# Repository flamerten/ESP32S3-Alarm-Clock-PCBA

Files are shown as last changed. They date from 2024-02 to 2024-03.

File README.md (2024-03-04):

# ESP32 S3 Alarm Clock PCBA
I used KiCAD to design an ESP32S3 based alarm clock. It includes an IMU (LSM6DSOX), a RTC (PCF8523) and 29 WS2812-2020 LEDs for showing the time via 7 segment digits. The PCB was manufactured and assembled via JLCPB. This repository includes the schematic, layout and Arduino script for testing the various functions on the board. The firmware based on ESP-IDF is still in progress.

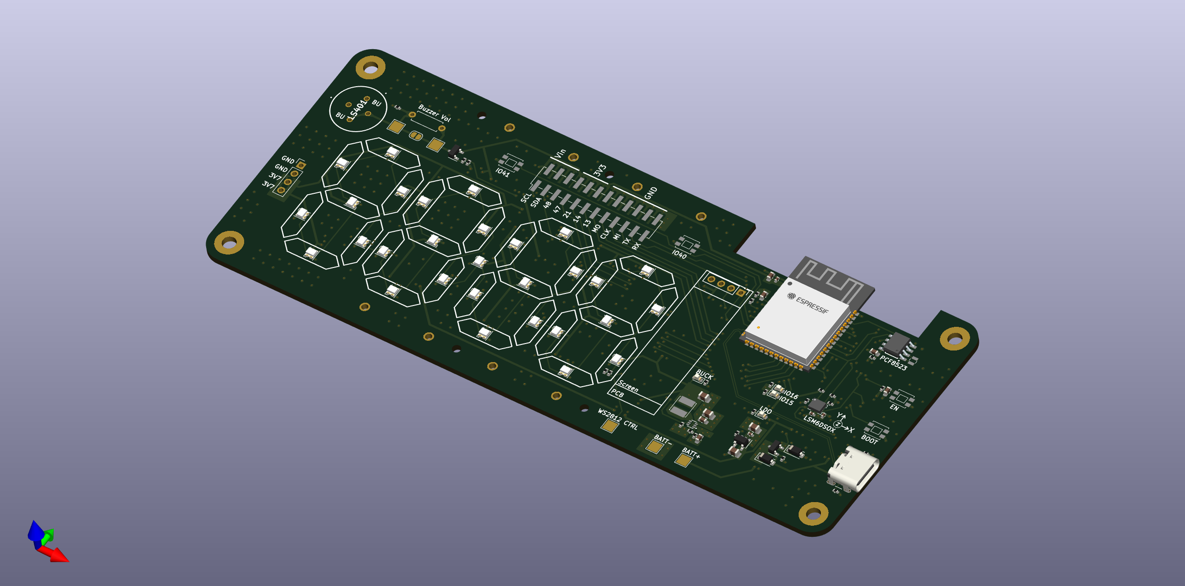
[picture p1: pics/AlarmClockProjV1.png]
Render

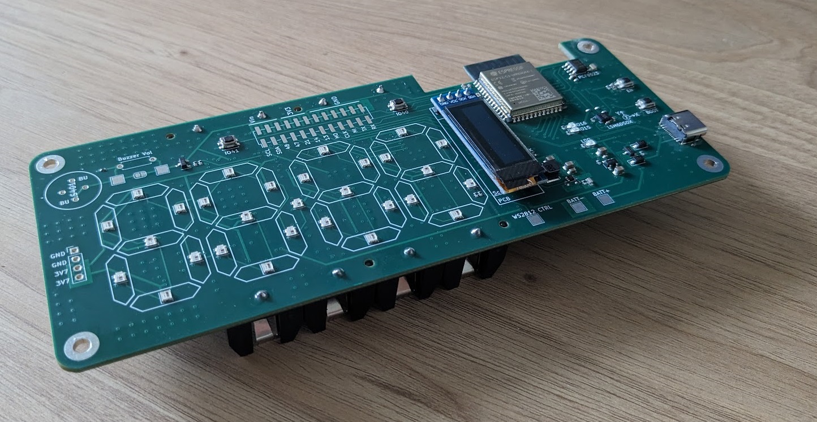
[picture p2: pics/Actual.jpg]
Actual


## Table of Contents
- [Schematic](#schematic)
- [Additional Notes](#additional-notes)

## Schematic
[Schematic Folder](./PCB/Schematic/)

The current schematic inlcudes some observations that I have made. For instance, I heard a high pitched noise from the switching regulator section, and that I could have added a switch to cut power to the whole board.

## Additional Notes
I used solidworks to design the dimensions of the 7-segment LED display, and converted it to a .dxf file format - [LED_Mapping.DXF](./LED_Mapping.DXF). This file was converted to a footprint and was used as a guide for the placement of LEDs.

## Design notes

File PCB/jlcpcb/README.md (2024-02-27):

# JLCPCB Files
Files in this folder are sent to JLCPCB for manufacturing. This file also includes the BOM and their respective LCSC parts. However, I sourced for the through hole components myself and soldered them.

- [Battery Holder](https://www.aliexpress.com/item/1005006254465094.html?spm=a2g0o)
- [OLED Breakout](https://www.aliexpress.com/item/1005005973981064.html?spm=a2g0o)
- [SMD Pin Header 02x12](https://www.aliexpress.com/item/33056177154.html?spm=a2g0o)
- [PS1240 Passive Buzzer](https://www.aliexpress.com/item/1005005731967986.html?spm=a2g0o)

## Ordering
I designed the PCB with KiCAD, and installed the [kicad-jlcpcb-tools](https://github.com/bouni/kicad-jlcpcb-tools) plugin which automatically generates the neccessary files. The [Gerber Files](./production_files/GERBER-AlarmClockProjV1.zip) are used first, followed by the [BOM File](./production_files/BOM-AlarmClockProjV1.csv) and [CPL File](./production_files/CPL-AlarmClockProjV1.csv). 

To reduce cost, I opted for single sided assembly, with no through hole components. The assembly was **standard** because of the ESP32 module and the WS2812B. 

I was recommended by JLCPCB to bake the WS2812-2020 component as it was moisture sensitive, which increased the assembly by $7.54.

Note that component rotation is mandatory. I had to check all the components and rotate them myself, not too sure why. Resistors and Capacitors were okay, but the MOSFETS, ICs and LEDs had to be rotated.

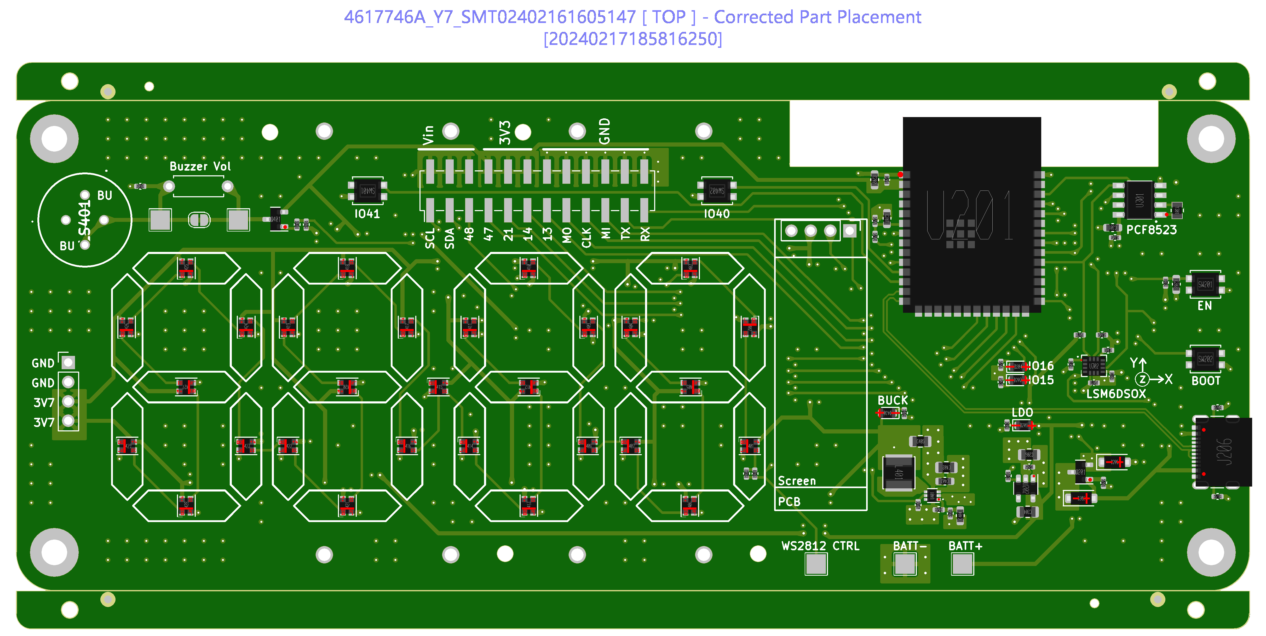
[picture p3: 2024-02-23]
PCB/jlcpcb/4617746A_Y7/49155830063104-Produce_DanZhi.SMT_Snapshot.Top.4617746A_Y7.SMT02402161605147.png

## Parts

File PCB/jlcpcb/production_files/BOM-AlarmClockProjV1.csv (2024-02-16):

Comment | Designator | Footprint | LCSC
1k | R204,R206,R208,R305,R401,R403,R404,R405,R409 | R_0402_1005Metric | C11702
100nF | C201,C205,C304,C305 | C_0402_1005Metric | C1525
ZXMP3A13FTA | Q201,Q401 | SOT-23-Alt | C156326
1uF | C202,C203,C207,C301,C403 | C_0603_1608Metric | C15849
10uF | C204,C206,C402,C405 | C_0805_2012Metric | C15850
33pF | C404 | C_0603_1608Metric | C190578
KT-0805Y | D201,D203,D204,D430 | LED_0603_1608Metric | C2296
100k | R202,R203,R205,R207 | R_0402_1005Metric | C25741
10k | R201,R301,R302,R303,R304,R402,R406,R408 | R_0402_1005Metric | C25744
5K1 | R209,R210 | R_0402_1005Metric | C25905
PCF8523T_1,118 | U301 | SOIC127P600X175-8N | C2651516
ESP32-S3-WROOM-1(N4) | U201 | ESP32S3WROOM1N8R8 | C2913197
RT5760CHGH6F | U401 | SOT-563 | C2976591
XKB Tactile | SW201,SW202,SW401,SW402 | XKB Tactile SW | C318879
51k | R407 | R_0402_1005Metric | C319542
1054500101 | J206 | USB_C_Receptacle_GCT_USB4105-xx-A_16P_TopMnt_Horizontal | C393939
4.7uH | L401 | GLE GCNR4030 4mmx4mm Inductor | C439356
LSM6DSOXTR | U302 | LSM6DSOX | C481766
AP2112K-3.3 | U202 | SOT-23-5 | C51118
BH-AA-A5BJ012 | J202,J203,J204,J205 | MYOUNG AA Bat Holder | C5290180
B5817W | D202,D205 | D_SOD-123 | C8597
PS1440P02BT | LS401 | PS1240P02BT | C96060
WS2812B-2020 | D401,D402,D403,D404,D405,D406,D407,D408,D409,D410,D411,D412,D413,D414,D415,D416,D417,D418,D419,D420,D421,D422,D423,D424,D425,D426,D427,D428,D429 | LED_WS2812B-2020_PLCC4_2.0x2.0mm | C965555
Seiko 32.768kHz | Y301 | Seiko Crustal | C99009
Conn_02x12_Odd_Even | J201 | PinHeader_2x12_P2.54mm_Vertical_SMD
Conn_01x04_Pin | J402 | PinHeader_1x04_P2.54mm_Vertical
Conn_01x04_Pin | J301 | 128x32_OLED_Breakout

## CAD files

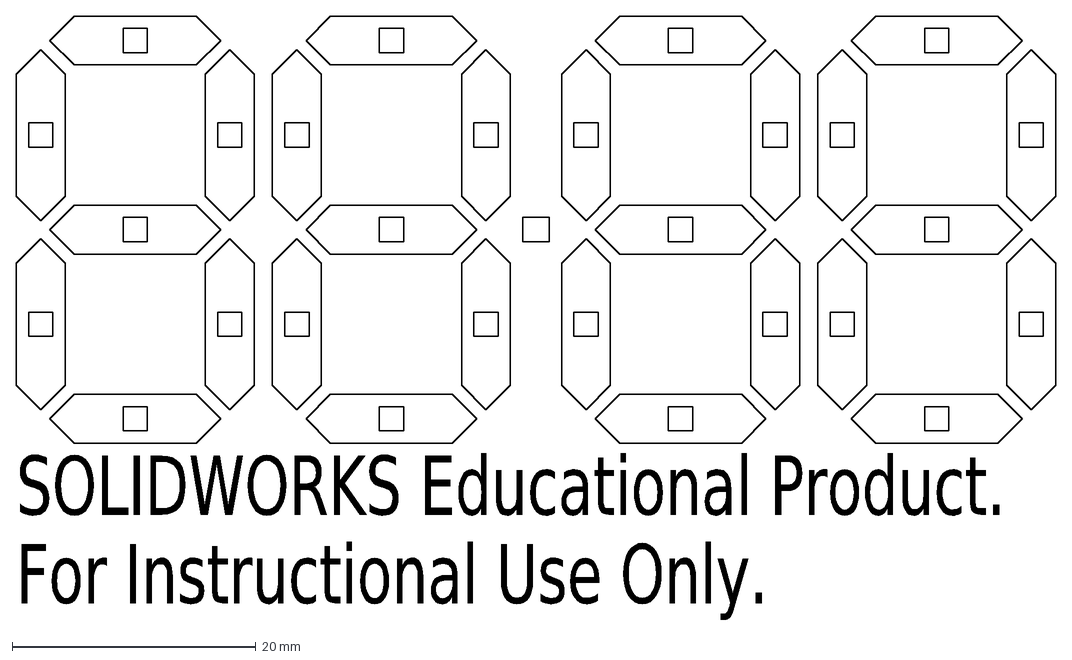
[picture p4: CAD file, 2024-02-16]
LED_Mapping.DXF
SOLIDWORKS Educational Product.
For Instructional Use Only.

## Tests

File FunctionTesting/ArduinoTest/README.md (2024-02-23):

# ArduinoTest

Used to test various functionalities of the PCB. 

## To Be Done
- Buzzer

## Arduino IDE Upload
[Source: USB and CDC Flashing](https://docs.espressif.com/projects/arduino-esp32/en/latest/tutorials/cdc_dfu_flash.html)

USB CDC is used to upload and view debugging messages
1. To enter into the download mode, you need to press and hold BOOT button and press and release the RESET button. You should see a new USB device with the name ESP32S3 Dev Kit listed in available ports. Select the device.
2. Configuration
- USB CDC On Boot -> Enabled
- Upload Mode -> UART0 / Hardware CDC
- USB Mode -> Hardware CDC & JTAG

Full configuration from "Tools" is here
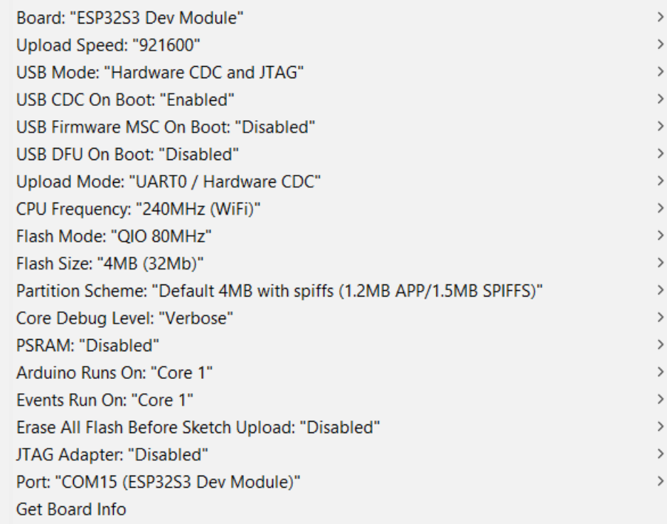
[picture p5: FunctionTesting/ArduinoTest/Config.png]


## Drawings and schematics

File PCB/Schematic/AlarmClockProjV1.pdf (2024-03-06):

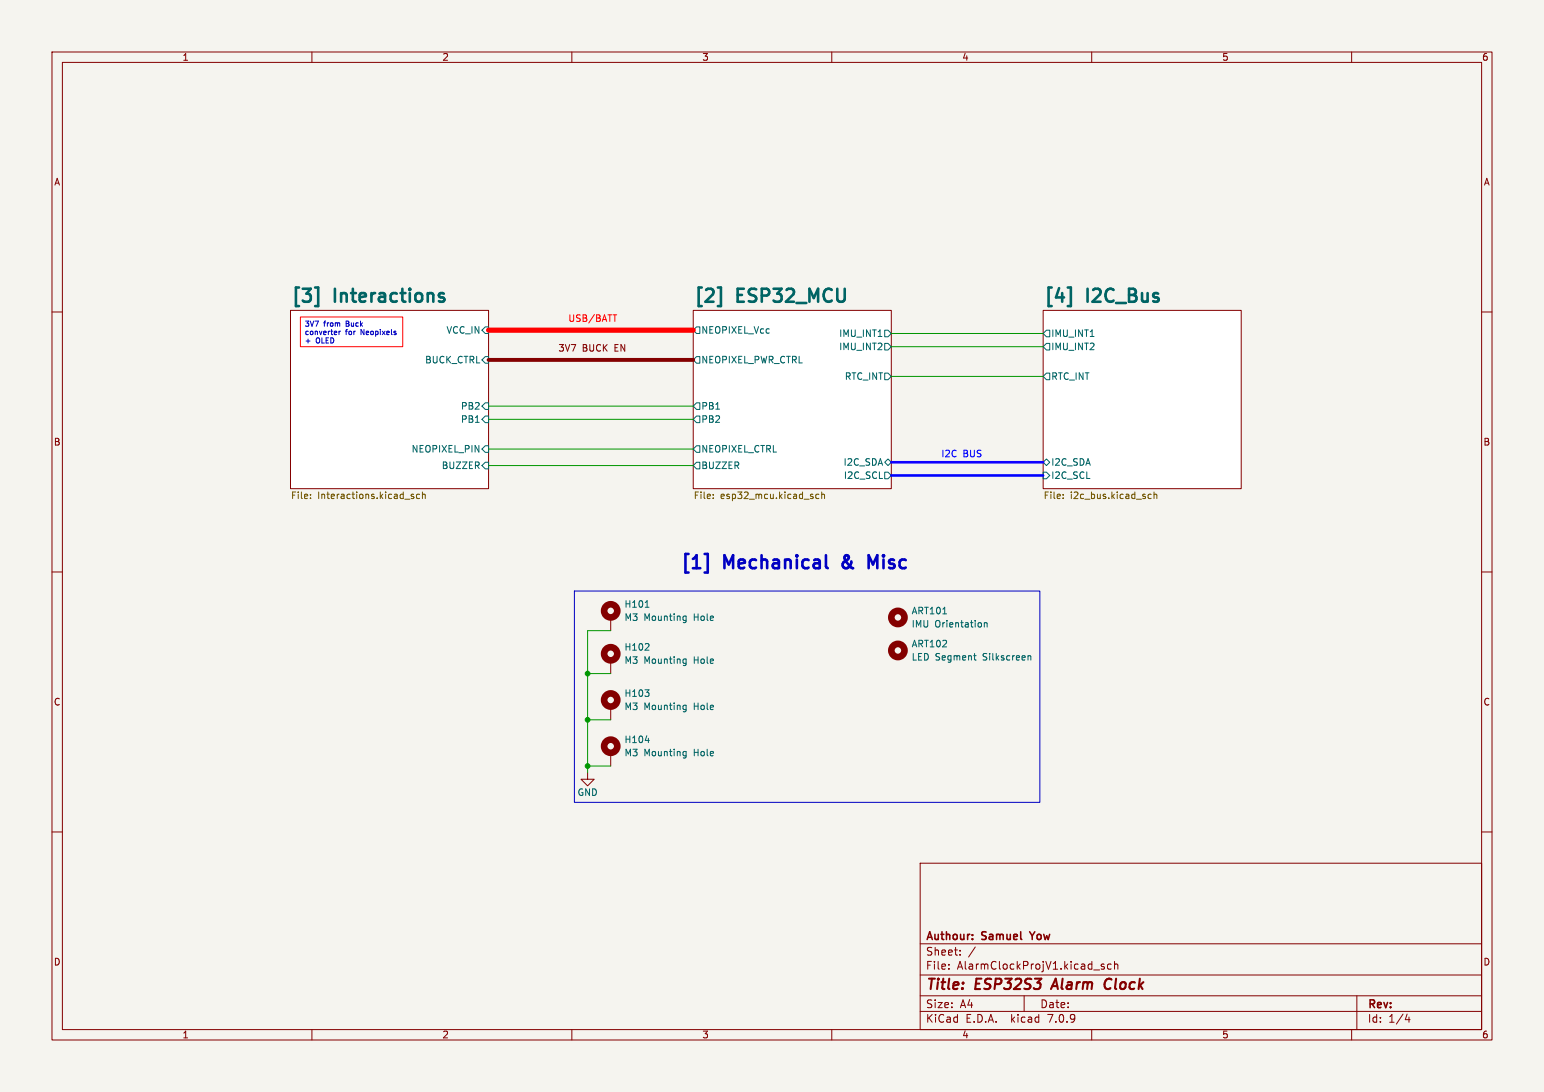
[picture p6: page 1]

IMU Orientation H101 M3 Mounting Hole GND

H103 M3 Mounting Hole H104 M3 Mounting Hole

File: AlarmClockProjV1.kicad_sch Sheet: / Authour: Samuel Yow

Id: 1/4 Title: ESP32S3 Alarm Clock

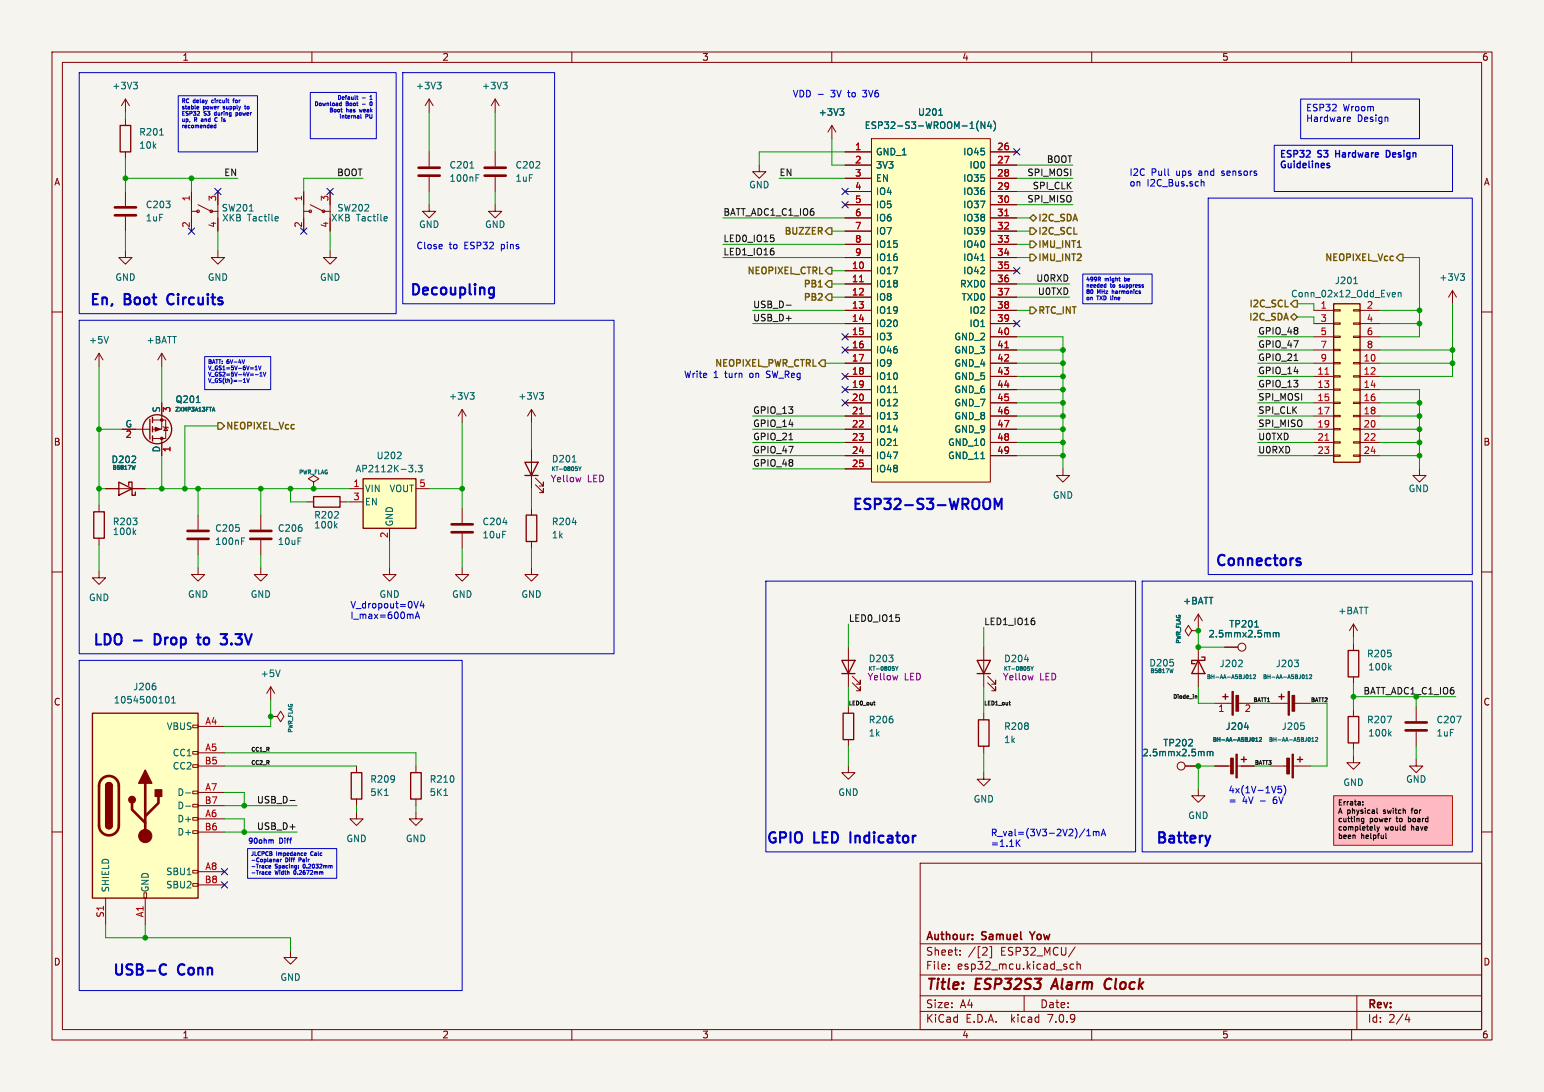
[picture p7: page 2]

VDD - 3V to 3V6 LDO - Drop to 3.3V
J201 Conn_02x12_Odd_Even R201

RC delay circuit for stable power supply to ESP32 S3 during power up, R and C is

3 4 SW202 XKB Tactile GND GND

Id: 2/4 Title: ESP32S3 Alarm Clock

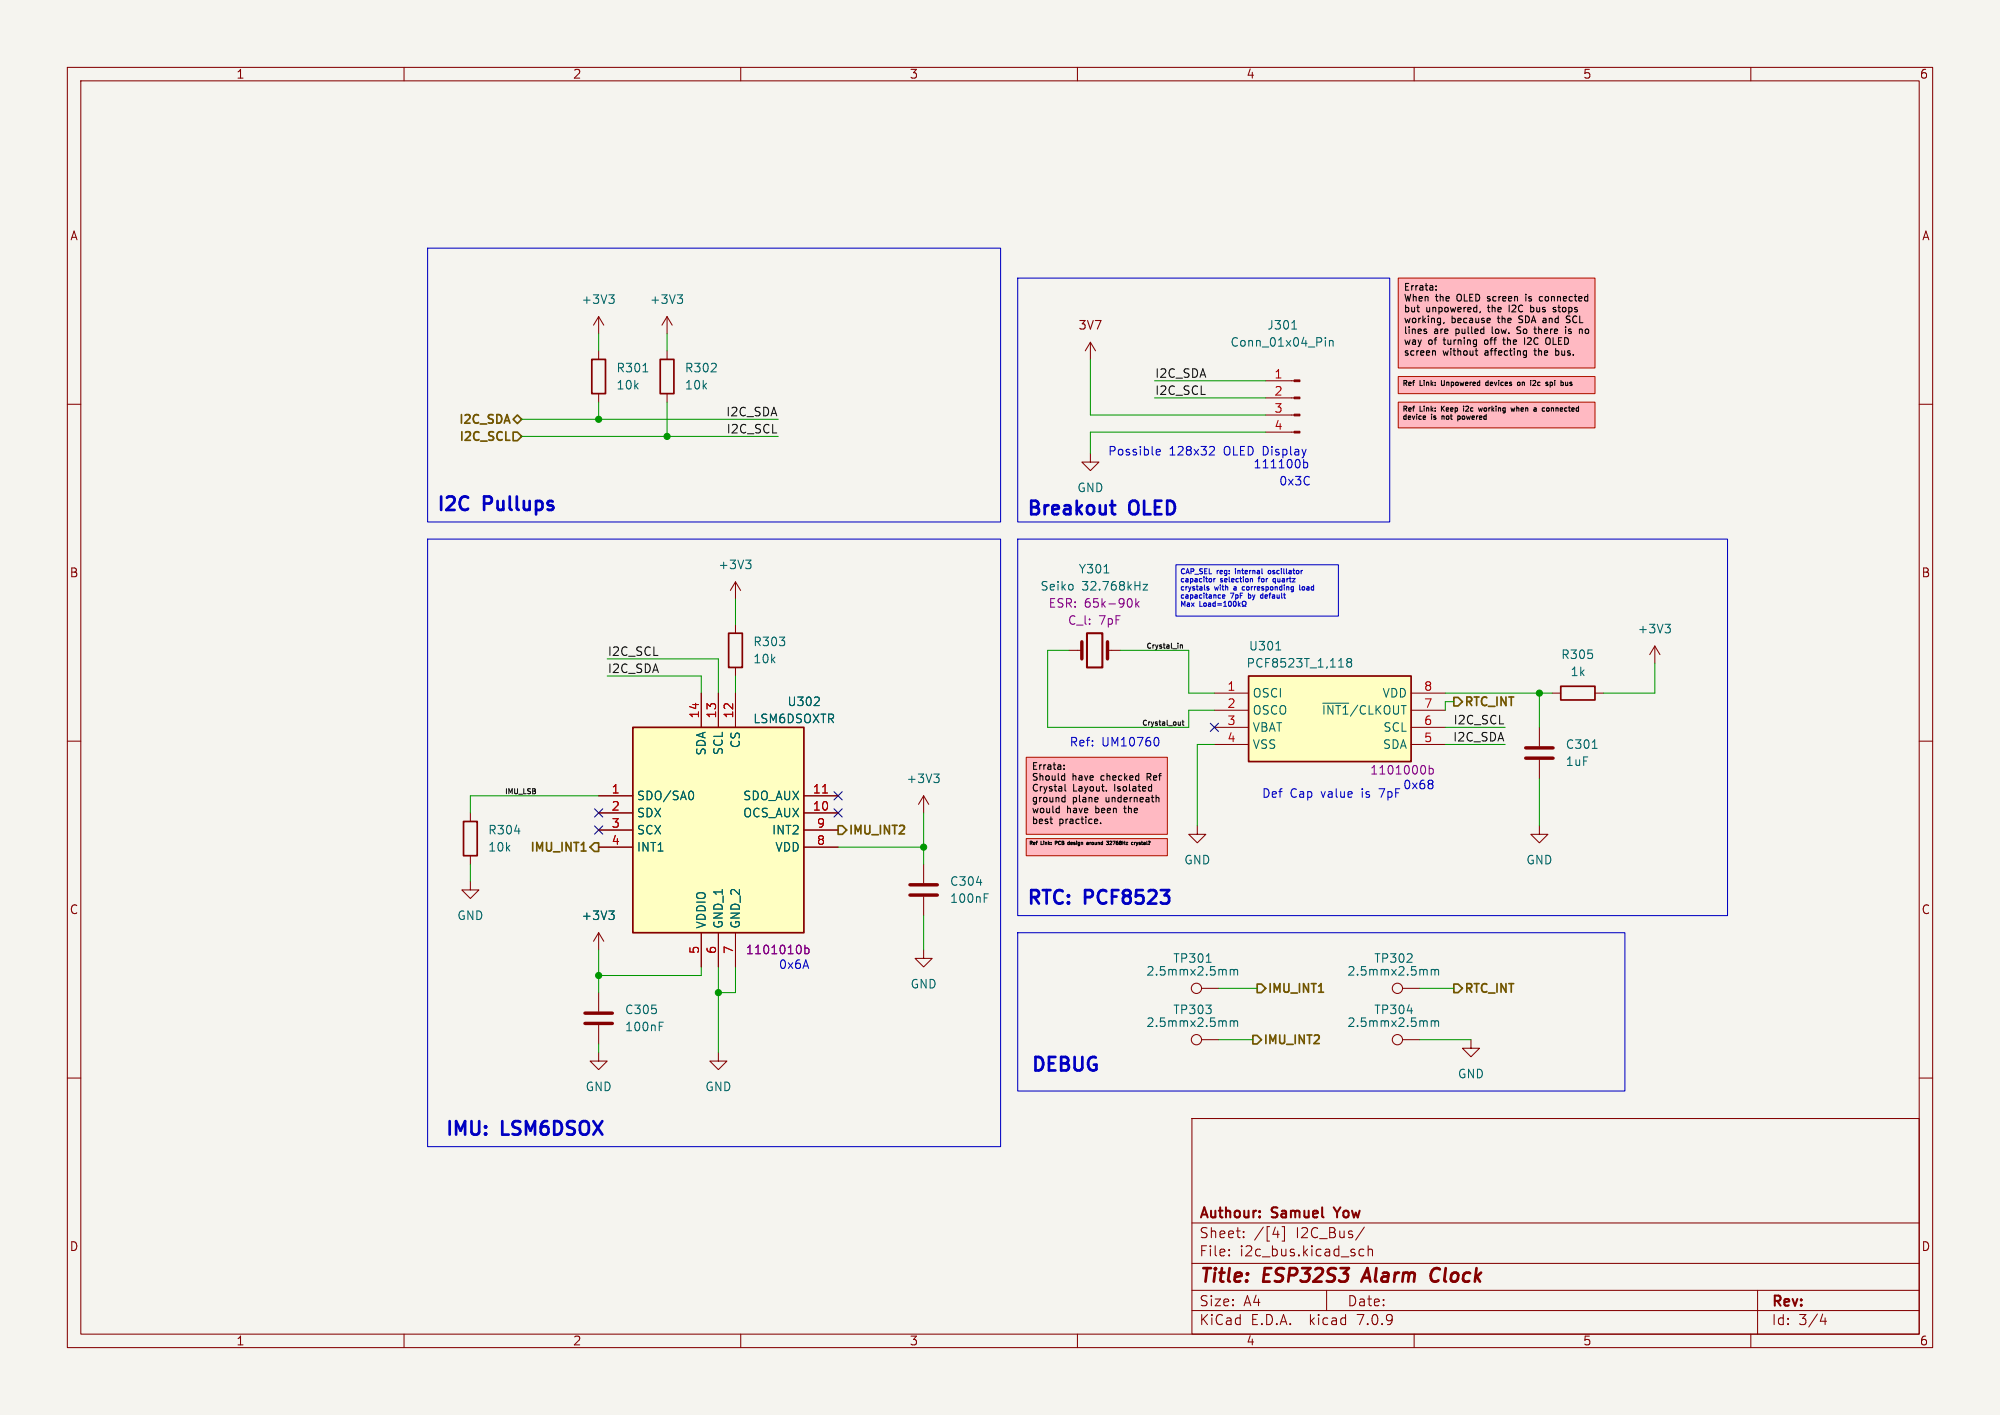
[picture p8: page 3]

device is not powered (https://forum.arduino.cc/t/keep-i2c-working-when-a-connected-device-is-not-powered/390732) Ref Link: Unpowered devices on i2c spi bus Errata: When the OLED screen is connected

Ref Link: Keep i2c working when a connected

Def Cap value is 7pF0x68

ground plane underneath would have been the

Id: 3/4 Title: ESP32S3 Alarm Clock

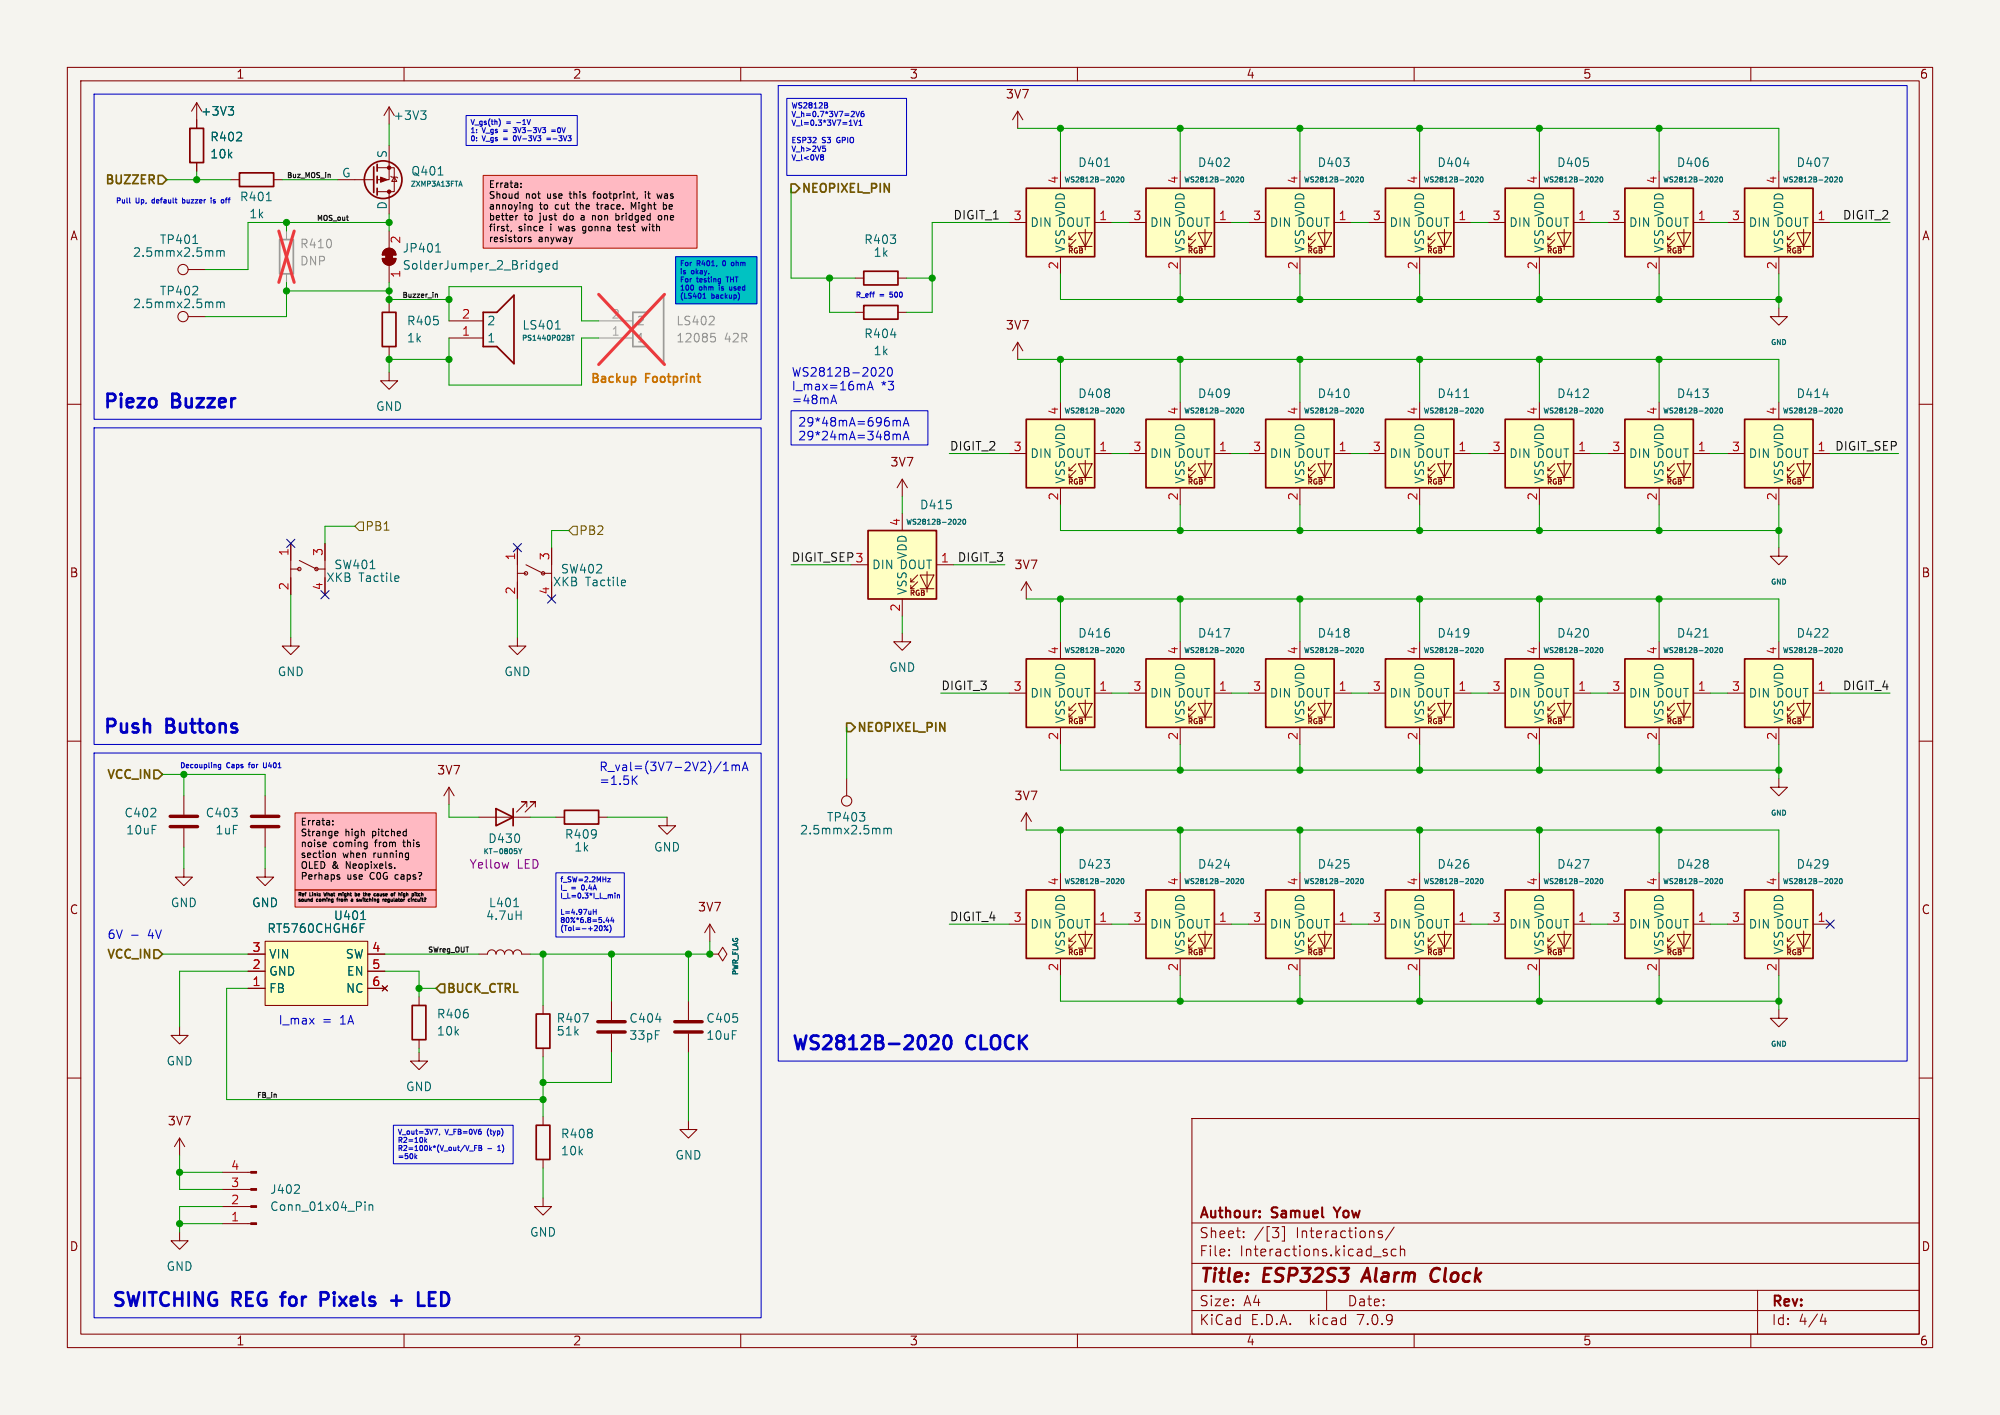
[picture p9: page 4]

4 D407 WS2812B-2020 GND GND RGB DOUT 1 VSS

better to just do a non bridged one
first, since i was gonna test with

Errata: Strange high pitched

noise coming from this

Ref Link: What might be the cause of high pitch

Id: 4/4 Title: ESP32S3 Alarm Clock

SWITCHING REG for Pixels + LED

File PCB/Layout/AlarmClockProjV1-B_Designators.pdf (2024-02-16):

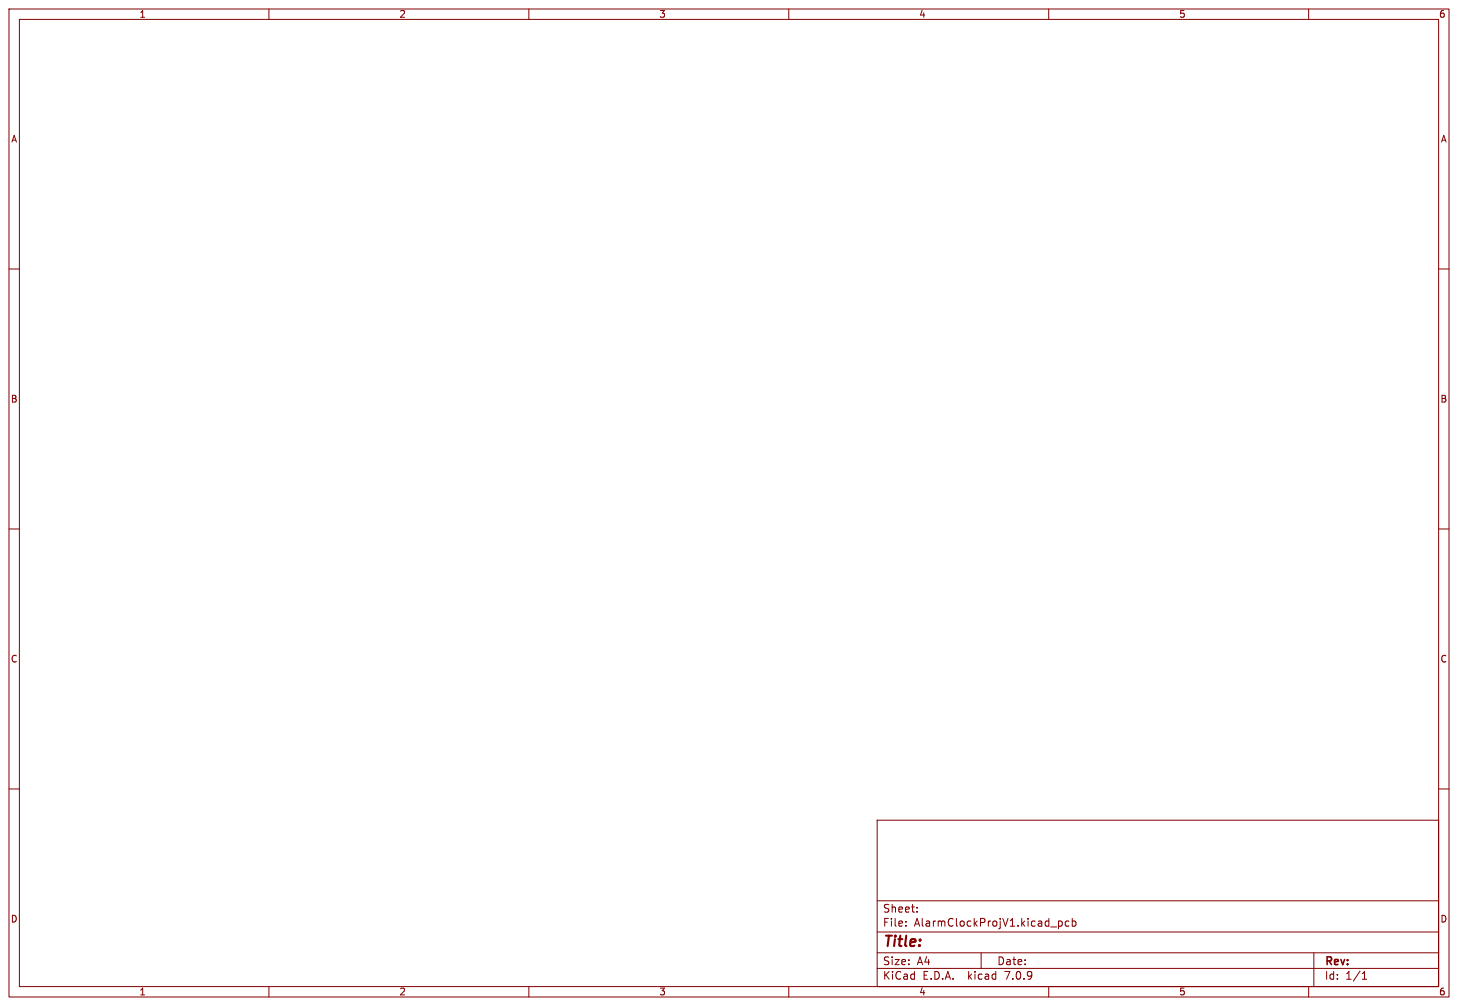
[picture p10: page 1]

Id: 1/1 Title: File: AlarmClockProjV1.kicad_pcb Sheet:

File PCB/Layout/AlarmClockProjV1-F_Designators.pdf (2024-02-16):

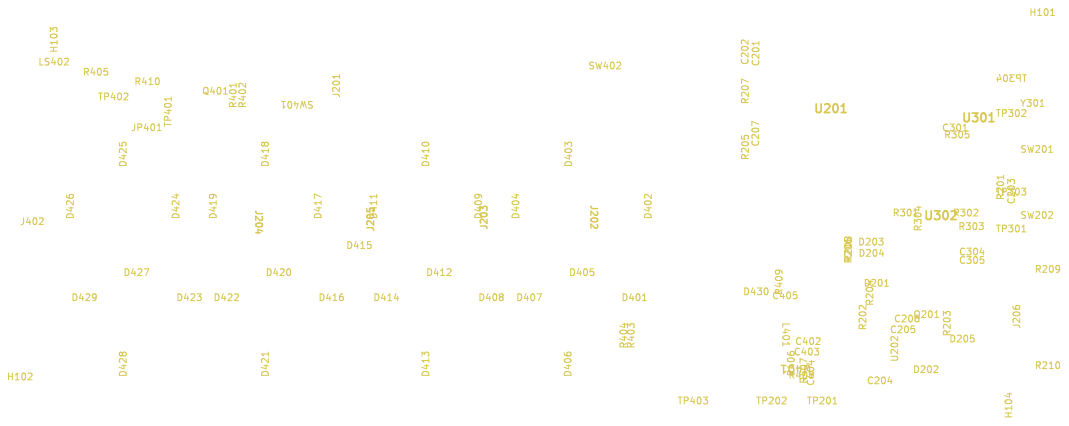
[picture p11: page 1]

Id: 1/1 Title: File: AlarmClockProjV1.kicad_pcb Sheet: R207

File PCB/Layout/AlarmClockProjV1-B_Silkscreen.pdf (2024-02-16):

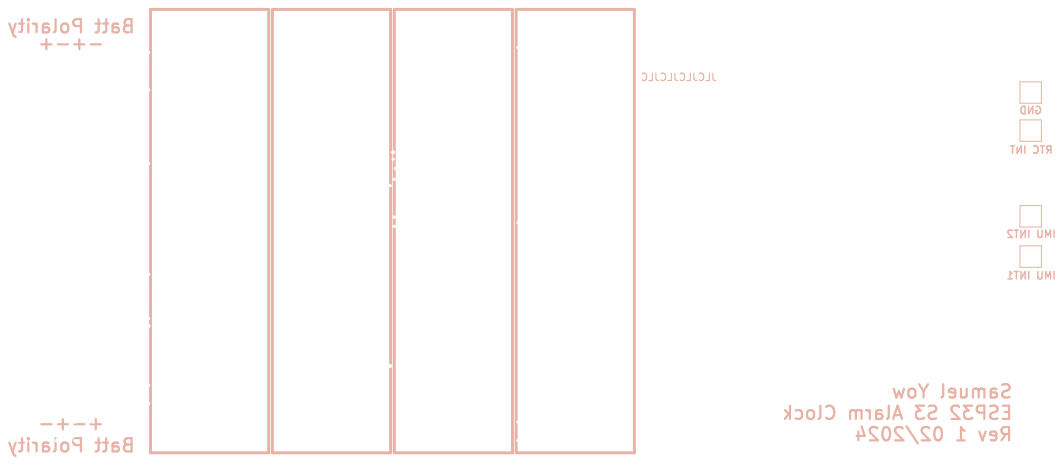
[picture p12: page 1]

Id: 1/1 Title: File: AlarmClockProjV1.kicad_pcb Sheet:

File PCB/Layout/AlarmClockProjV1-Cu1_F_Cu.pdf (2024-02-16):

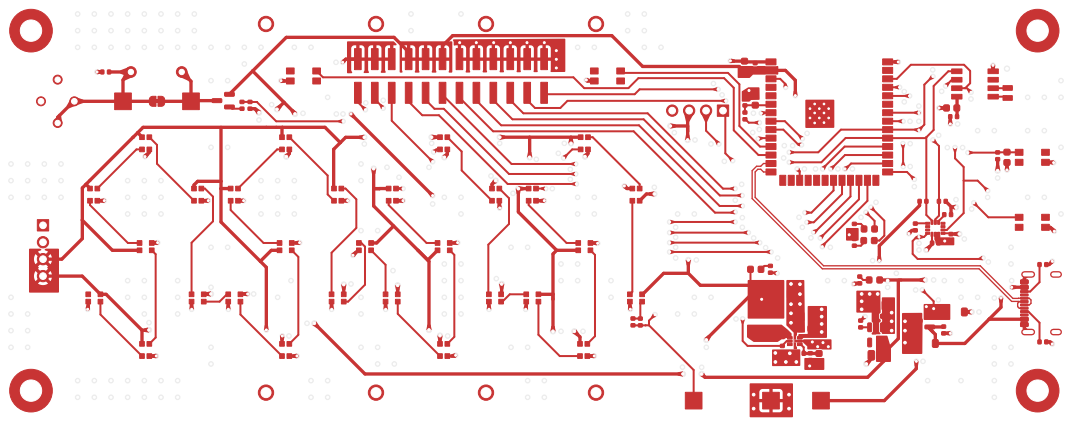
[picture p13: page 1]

Id: 1/1 Title: File: AlarmClockProjV1.kicad_pcb Sheet:

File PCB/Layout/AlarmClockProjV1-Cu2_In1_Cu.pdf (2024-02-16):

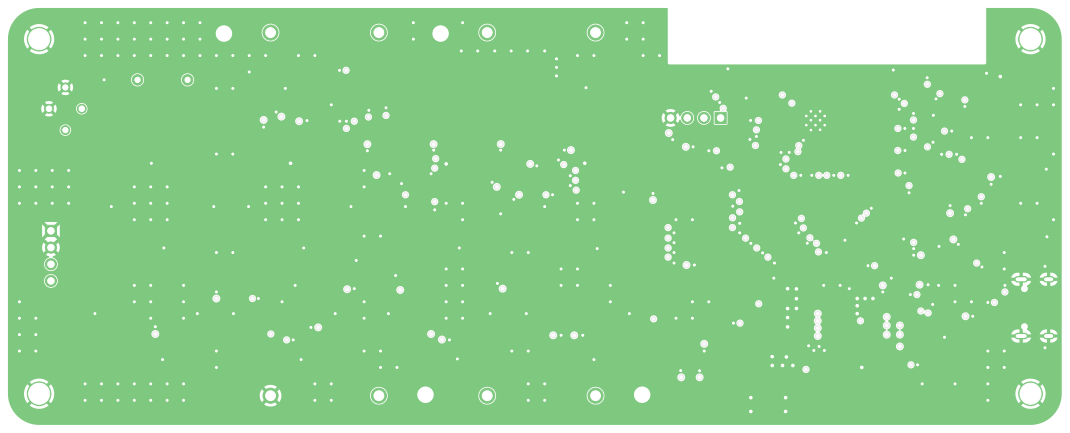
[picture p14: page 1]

Id: 1/1 Title: File: AlarmClockProjV1.kicad_pcb Sheet:

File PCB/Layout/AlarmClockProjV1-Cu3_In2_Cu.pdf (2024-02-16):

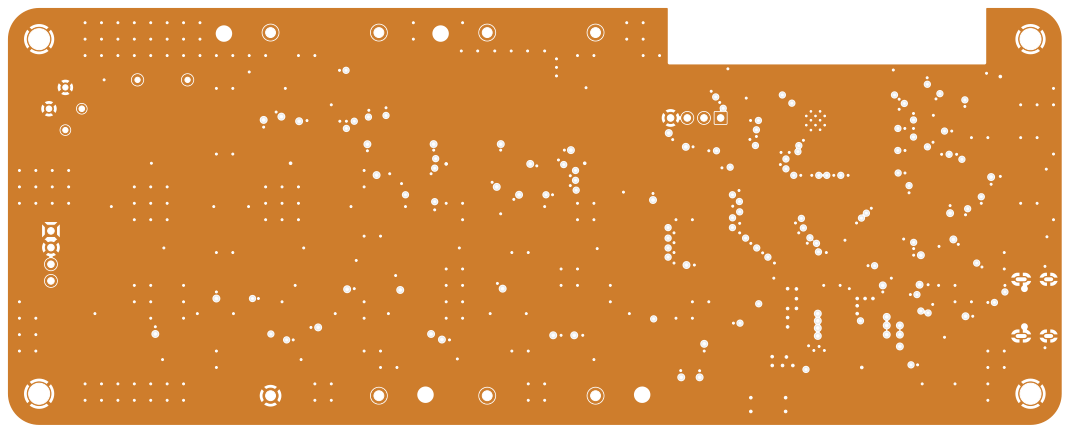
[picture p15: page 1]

Id: 1/1 Title: File: AlarmClockProjV1.kicad_pcb Sheet:

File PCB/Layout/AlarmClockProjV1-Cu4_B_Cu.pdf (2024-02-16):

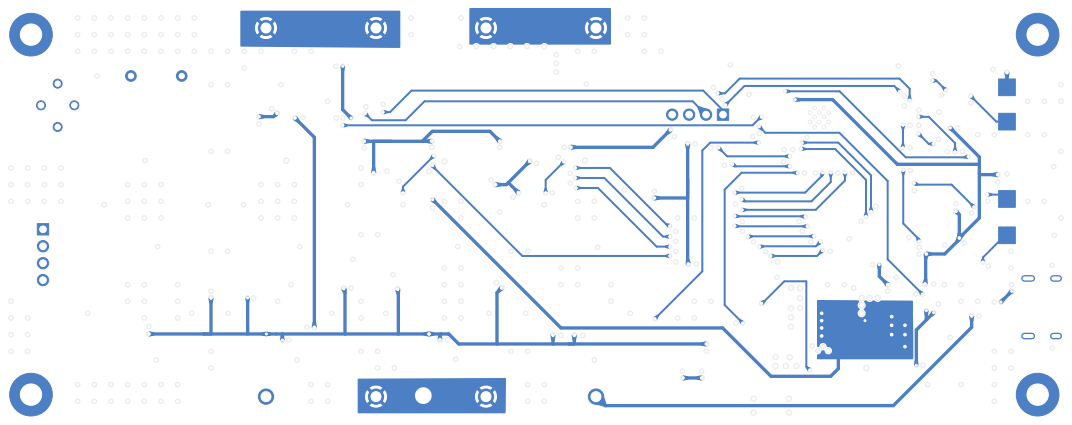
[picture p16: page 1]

Id: 1/1 Title: File: AlarmClockProjV1.kicad_pcb Sheet:

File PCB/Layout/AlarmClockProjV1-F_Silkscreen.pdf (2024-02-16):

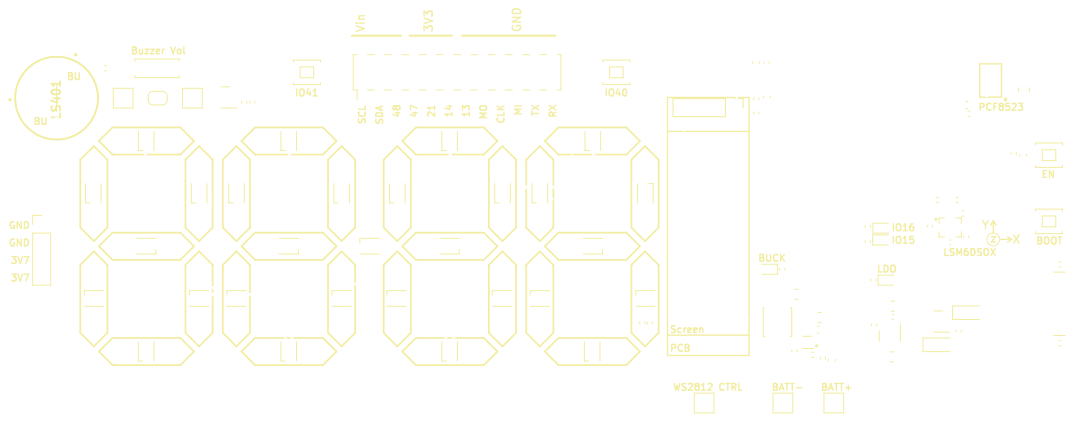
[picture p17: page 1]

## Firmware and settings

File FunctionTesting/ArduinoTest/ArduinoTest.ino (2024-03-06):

/*
 * Script for testing various functionalities of the PCB
 */

#include <Wire.h>
#include <Adafruit_NeoPixel.h>
#include <Adafruit_SSD1306.h>
#include <Adafruit_GFX.h>
#include <RTClib.h>
#include <Adafruit_LSM6DSOX.h> 
#include "pitches.h"

#define BUZZER 7
#define NEOPIXEL_CTRL 17
#define PB1 18
#define PB2 8
#define PCB_I2C_SDA 38
#define PCB_I2C_SCL 39
#define IMU_INT1 40
#define IMU_INT2 41
#define RTC_INT  2
#define SWREG_CTRL 9
#define BUZZER_PIN 7
#define BUZZER_CHANNEL 0

#define LED_COUNT 30

Adafruit_LSM6DSOX imu;
RTC_PCF8523 rtc;
Adafruit_NeoPixel strip(LED_COUNT, NEOPIXEL_CTRL, NEO_GRB + NEO_KHZ800);

#define SCREEN_WIDTH 128 // OLED display width, in pixels
#define SCREEN_HEIGHT 32 // OLED display height, in pixels
#define OLED_RESET     -1 // Reset pin # (or -1 if sharing Arduino reset pin)
#define SCREEN_ADDRESS 0x3C ///< See datasheet for Address; 0x3D for 128x64, 0x3C for 128x32

//Function Def
void test_i2c_devices();
void test_neopixel();
void test_oled();
void imu_test_print();
void beep( int note, int duree );
void HappyBirthday();

void setup() {
  // put your setup code here, to run once:
  Serial.begin(115200);
  delay(1000);

  Serial.println("Hello PCB");
  delay(1000);

  //LEDs
  Serial.println("LED Test");
  pinMode(15,OUTPUT);
  pinMode(16,OUTPUT);
  
  digitalWrite(15,HIGH);
  digitalWrite(16,HIGH);

  Wire.begin(PCB_I2C_SDA,PCB_I2C_SCL);
  delay(1000);

  i2c_addr_scan();

  test_i2c_devices();

  //3V7 powers OLED and pixels
  pinMode(SWREG_CTRL,OUTPUT);
  digitalWrite(SWREG_CTRL,HIGH);
  
  Serial.println("Try with 3V7 on");
  i2c_addr_scan();
  test_oled();

  strip.begin();
  strip.clear();
  strip.setBrightness(20);
}

void loop() {
  imu_test_print();
  HappyBirthday();
  test_neopixel();

}

void test_neopixel()
{
  Serial.println("Start test");

  for(int i=0; i<LED_COUNT; i++) {

    strip.setPixelColor(i, strip.Color(0, 150, 0));
    strip.show();
    delay(500);
  }

  for(int i=0; i<LED_COUNT; i++) {

    strip.setPixelColor(i, strip.Color(150, 0, 0));
    strip.show();
    delay(500);
  }

  for(int i=0; i<LED_COUNT; i++) {

    strip.setPixelColor(i, strip.Color(0, 0, 150));
    strip.show();
    delay(500);
  }  

  Serial.println("Neopixel test done");
}

void test_i2c_devices()
{ 
  Serial.println("I2C Device Test");
  
  if(!imu.begin_I2C()){
    Serial.println("Unable to find LSM6DSOX");
  }
  else{
    Serial.println("IMU Found");
  }

  if(!rtc.begin()){
    Serial.println("Unable to find PCF8523");
  }
  else{
    Serial.println("RTC Found");
  }
  
  Serial.println("I2C testing done");
  
}

void test_oled()
{ 
  Adafruit_SSD1306 display(SCREEN_WIDTH, SCREEN_HEIGHT, &Wire, OLED_RESET);
  delay(100);
  Serial.println("OLED display test");
  
  if(!display.begin(SSD1306_SWITCHCAPVCC, SCREEN_ADDRESS)) {
    Serial.println(F("SSD1306 allocation failed"));
  } 
  else{
    Serial.println("OLED OK");
  }

  display.display();
  delay(2000); // Pause for 2 seconds
  display.clearDisplay();

  display.fillRect(0,0,display.width(),display.height(),SSD1306_WHITE);
  display.display();
}


void i2c_addr_scan()
{
  byte error, address;
  int nDevices;
 
  Serial.println("Scanning...");
 
  nDevices = 0;
  for(address = 1; address < 127; address++ )
  {
    // The i2c_scanner uses the return value of
    // the Write.endTransmisstion to see if
    // a device did acknowledge to the address.
    Wire.beginTransmission(address);
    error = Wire.endTransmission();
 
    if (error == 0)
    {
      Serial.print("I2C device found at address 0x");
      if (address<16)
        Serial.print("0");
      Serial.print(address,HEX);
      Serial.println("  !");
 
      nDevices++;
    }
    else if (error==4)
    {
      Serial.print("Unknown error at address 0x");
      if (address<16)
        Serial.print("0");
      Serial.println(address,HEX);
    }    
  }
  if (nDevices == 0)
    Serial.println("No I2C devices found\n");
  else
    Serial.println("done\n");
 
  delay(5000);           // wait 5 seconds for next scan
}

void imu_test_print()
{
  // put your main code here, to run repeatedly:
  sensors_event_t accel;
  sensors_event_t gyro;
  sensors_event_t temp;
  imu.getEvent(&accel, &gyro, &temp);  

    /* Display the results (acceleration is measured in m/s^2) */
  Serial.print("\t\tAccel X: ");
  Serial.print(accel.acceleration.x);
  Serial.print(" \tY: ");
  Serial.print(accel.acceleration.y);
  Serial.print(" \tZ: ");
  Serial.print(accel.acceleration.z);
  Serial.println(" m/s^2 ");

  /* Display the results (rotation is measured in rad/s) */
  Serial.print("\t\tGyro X: ");
  Serial.print(gyro.gyro.x);
  Serial.print(" \tY: ");
  Serial.print(gyro.gyro.y);
  Serial.print(" \tZ: ");
  Serial.print(gyro.gyro.z);
  Serial.println(" radians/s ");
  Serial.println();  
}

void beep( int note, int noteDuration ) {
  int pauseBetweenNotes = noteDuration * 1.30;
  tone(BUZZER,note,noteDuration);
  delay(pauseBetweenNotes);     
  noTone(BUZZER);
  delay(noteDuration*0.25);
}

void HappyBirthday() {
  Serial.println("Starting Buzzer Test: Happy Birthday");
  
  beep(NOTE_G3, 200);
  beep(NOTE_G3, 200);
  beep(NOTE_A3, 500);
  beep(NOTE_G3, 500);
  beep(NOTE_C4, 500);
  beep(NOTE_B3, 1000);
  beep(NOTE_G3, 200);
  beep(NOTE_G3, 200);
  beep(NOTE_A3, 500);
  beep(NOTE_G3, 500);
  beep(NOTE_D4, 500);
  beep(NOTE_C4, 1000);
  beep(NOTE_G3, 200);
  beep(NOTE_G3, 200);
  beep(NOTE_G4, 500);
  beep(NOTE_E4, 500);
  beep(NOTE_C4, 500);
  beep(NOTE_B3, 500);
  beep(NOTE_A3, 750);
  beep(NOTE_F4, 200);
  beep(NOTE_F4, 200);
  beep(NOTE_E4, 500);
  beep(NOTE_C4, 500);
  beep(NOTE_D4, 500);
  beep(NOTE_C4, 1000); 
}

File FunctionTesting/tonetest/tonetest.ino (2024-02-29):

#include "pitches.h"

#define BUZZER_GPIO 7

void play_tone();

// notes in the melody:
int melody[] = {

  NOTE_C4, NOTE_G3, NOTE_G3, NOTE_A3, NOTE_G3, 0, NOTE_B3, NOTE_C4
};

// note durations: 4 = quarter note, 8 = eighth note, etc.:
int noteDurations[] = {

  4, 8, 8, 4, 4, 4, 4, 4
};

void setup() {

  // iterate over the notes of the melody:


}

void loop() {

  play_tone();

  delay(5000);
}

void play_tone()
{
  for (int thisNote = 0; thisNote < 8; thisNote++) {

    // to calculate the note duration, take one second divided by the note type.

    //e.g. quarter note = 1000 / 4, eighth note = 1000/8, etc.

    int noteDuration = 1000 / noteDurations[thisNote];

    tone(BUZZER_GPIO, melody[thisNote], noteDuration);

    // to distinguish the notes, set a minimum time between them.

    // the note's duration + 30% seems to work well:

    int pauseBetweenNotes = noteDuration * 1.30;

    delay(pauseBetweenNotes);

    // stop the tone playing:

    noTone(BUZZER_GPIO);

  }  
}

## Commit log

2024-02-16 sent to jlcpcb
    [AlarmClockProjV1-CuBottom.gbr, AlarmClockProjV1-CuIn1.gbr, AlarmClockProjV1-CuIn2.gbr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]
2024-02-16 remove gerber zip
2024-02-16 add schematic to README
2024-02-23 JLCPCB Production files & Arduino Testing
2024-02-27 file rearrangment, update schema and READMEs
    [AlarmClockProjV1-CuBottom.gbr, AlarmClockProjV1-CuIn1.gbr, AlarmClockProjV1-CuIn2.gbr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]
2024-03-06 Update errata in schematic
    [ArduinoTest.ino]
